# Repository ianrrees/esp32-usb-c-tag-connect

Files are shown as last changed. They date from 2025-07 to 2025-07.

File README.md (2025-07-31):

# ESP32 USB Development Tool

This board adapts USB (either a type-C socket or a cable) to a Tag Connect
TC2030-compatible footprint, for use with ESP32 such as ESP32-S3 that provide
on-chip USB JTAG and UART functionality.  The Tag Connect footprint is
compatible with the
[TC2030-USB](https://www.tag-connect.com/product/tc2030-usb), replacing the two
N/C pins in that footprint with EN and IO0, used for reset and bootloader
buttons.

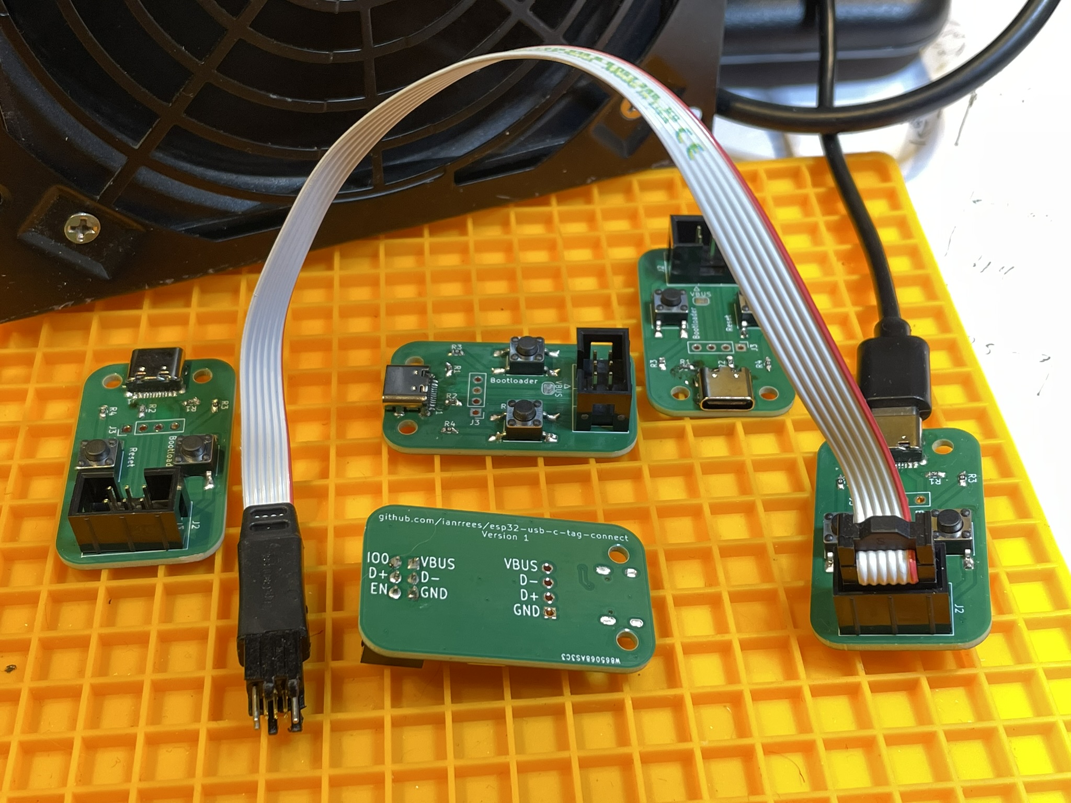
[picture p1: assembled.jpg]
Five assembled boards


## Pinouts

| J2 | | Tag Connect header |
|---|---|---|
| 1 | VBUS | USB VBUS +5V |
| 2 | IO0  | Hold low during reset to stay in bootloader  |
| 3 | D- | USB data |
| 4 | D+ | USB data |
| 5 | GND  | Ground |
| 6 | EN | Pull low to reset the ESP32 |

| J3 | USB cable termination |
|----|---|
| 1  | GND |
| 2  | D+ |
| 3  | D- |
| 4  | VBUS |

## BOM

| Qty | Refdes | Description |
|---|---|---|
| 1 | | PCB - [available from PCBWay](https://www.pcbway.com/project/shareproject/USB_C_to_Tag_Connect_TC2030_for_ESP32_USB_debugging_v1_5e1c53b1.html) |
| 1 (optional) | J1 | aliexpress 16-pin USB-C connector |
| 2 | Reset, Bootloader | aliexpress 6x6x5 SMD tactile button switch |
| 2 | R3, R4 | 0603 0 Ohm |
| 2 | R1, R2 | 0603 1.5k Ohm |
| 1 | J2 | 2x6 0.1" box header |

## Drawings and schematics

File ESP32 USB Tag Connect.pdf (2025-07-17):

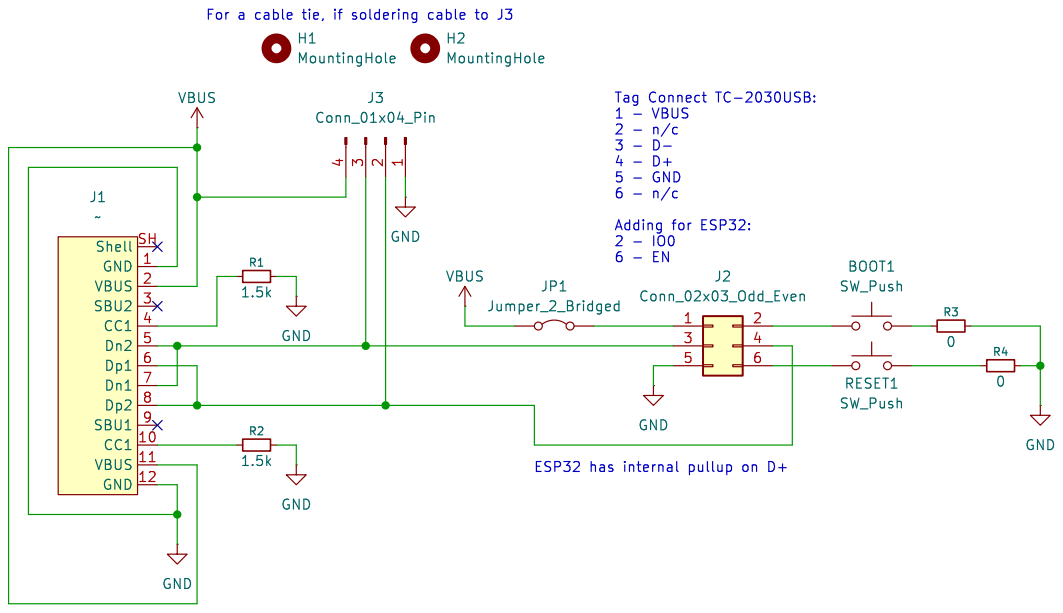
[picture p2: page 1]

Tag Connect TC-2030USB: 1 - VBUS

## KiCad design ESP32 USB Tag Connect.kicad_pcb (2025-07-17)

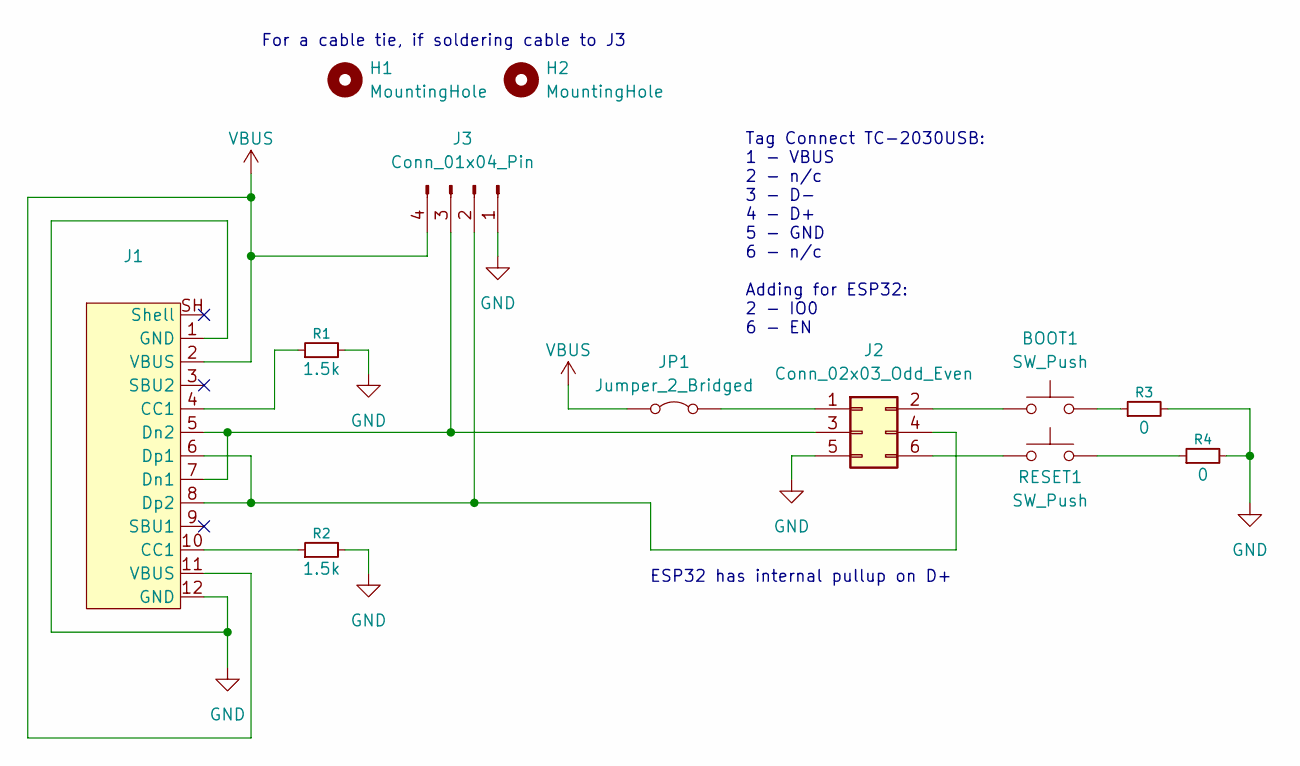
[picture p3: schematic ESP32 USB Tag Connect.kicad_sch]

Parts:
BOOT1: SW_Push; SW_Push_1P1T_NO_E-Switch_TL3301NxxxxxG
H1, H2: MountingHole; MountingHole_3mm
J1: USB-C 16 pin socket
J2: Conn_02x03_Odd_Even; IDC-Header_2x03_P2.54mm_Vertical
J3: Conn_01x04_Pin; PinHeader_1x04_P2.54mm_Vertical
JP1: Jumper_2_Bridged; SolderJumper-2_P1.3mm_Bridged_RoundedPad1.0x1.5mm
R1, R2: 1.5k; R_0603_1608Metric_Pad0.98x0.95mm_HandSolder
R3, R4: 0; R_0603_1608Metric_Pad0.98x0.95mm_HandSolder
RESET1: SW_Push; SW_Push_1P1T_NO_E-Switch_TL3301NxxxxxG

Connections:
GND: J1.1 (GND), J1.12 (GND), J2.5, J3.1, R1.2, R2.2, R3.2, R4.2
unnamed: BOOT1.2, R3.1
unnamed: J1.4 (CC1), R1.1
unnamed: J1.10 (CC1), R2.1
unnamed: J1.5 (Dn2), J1.7 (Dn1), J2.3, J3.3
unnamed: J1.6 (Dp1), J1.8 (Dp2), J2.4, J3.2
unnamed: J2.1, JP1.2 (B)
unnamed: BOOT1.1, J2.2
unnamed: J2.6, RESET1.1
unnamed: R4.1, RESET1.2
VBUS: J1.2 (VBUS), J1.11 (VBUS), J3.4, JP1.1 (A)

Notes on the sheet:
ESP32 has internal pullup on D+
Tag Connect TC-2030USB: 1 - VBUS 2 - n/c 3 - D- 4 - D+ 5 - GND 6 - n/c Adding for ESP32: 2 - IO0 6 - EN
For a cable tie, if soldering cable to J3

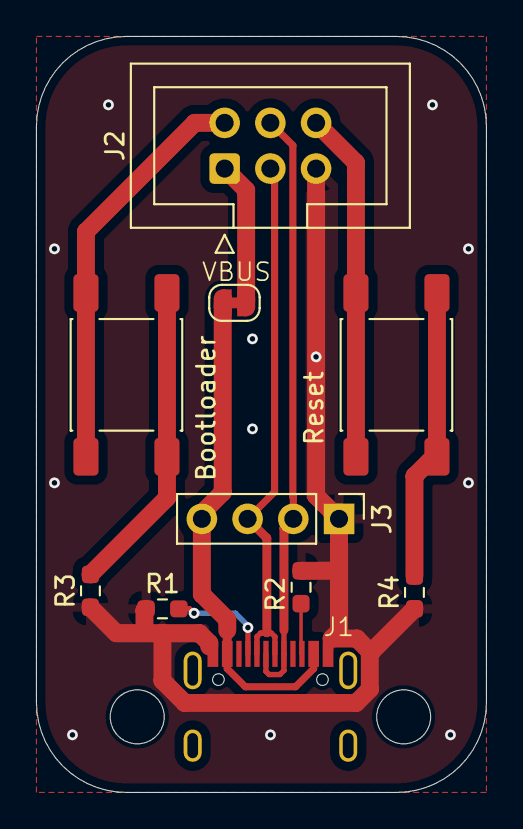
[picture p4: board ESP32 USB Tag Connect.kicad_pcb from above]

Board: 2 copper layers, 25.0 x 42.0 mm, 12 parts (0 on the bottom side), 11 nets.
